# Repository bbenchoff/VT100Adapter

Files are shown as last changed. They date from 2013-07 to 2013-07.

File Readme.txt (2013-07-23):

VT100 to ATX power supply adapter

This project adapts an off-the-shelf computer power supply to replace the power supply found in a Digital VT100 serial terminal.

As of now, this will not work with a VT103, as it does not generate BPOK and BDCOK signals. It should, however, work with the VT101 and VT102.

The terminal is not mounted to the PCB, allowing for positioning in various locations in the power supply bay of the VT100.

Included in this repo are Eagle schematic and board files, Gerbers in OSHPark format, and a BOM with Mouser listings of every component.

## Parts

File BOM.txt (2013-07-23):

Part Value      Device      	Package               Description           			P/N

C1   220uF 50V  CAP_POLPTH1 	CPOL-RADIAL-100UF-25V Capacitor Polarized                                                                                                                                                                                                   
C2   0.01 uF    CAPEZ       	CAP-PTH-SMALLEZ       Capacitor                                                                                                                                                                                                             
J1   ATX24RH    ATX24RH     	ATX24_RIGHT_ANGLE     ATX24 Pin PRT-09498    			Mouser 538-39-30-0240

R1   6.8 Ohm	Resistor			      Wire-wound Resistor			Mouser 756-WHS5-6R8JT075
                                                      
U1   DFBRIDGE   Diode Bridge			                                               	Mouser 625-DF04MA-E3                                                                                                                                                                                    
U2   7824T      7824T       	TO220H                Positive Voltage Regulator	       	Mouser 755-BA17824T                                                                                                                                                                      
X1   X1           	    		              Terminal Block                            Mouser 571-282856-2                                                                                                                                                 
X2   X2           	    		              Terminal Block                            Mouser 571-282856-2

T1		Transformer			      Power Transformers 115/230 6VA 24VCT	Mouser 546-186B24

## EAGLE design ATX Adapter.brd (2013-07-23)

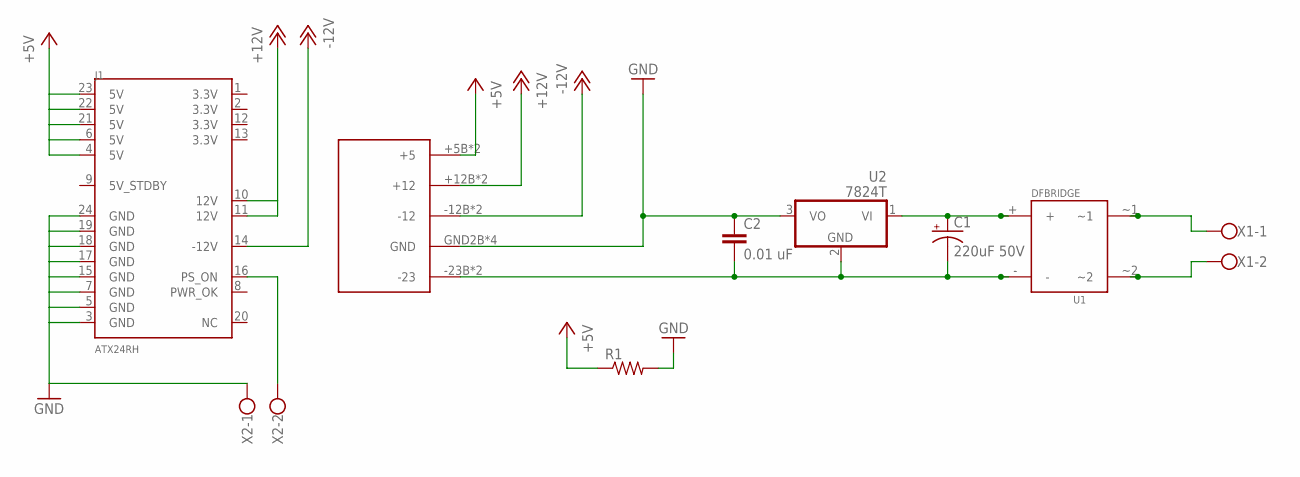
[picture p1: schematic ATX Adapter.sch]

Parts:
C1: 220uF 50V; CPOL-RADIAL-100UF-25V
C2: 0.01 uF; CAP-PTH-SMALLEZ
J1: ATX24RH; ATX24_RIGHT_ANGLE
R1: RESISTORPTH-2W; AXIAL-0.8
U1: DFBRIDGE
U2: 7824T; TO220H
U$1: VT100POWER
X1, X2: W237-102

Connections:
+5V: J1.4 (5V), J1.6 (5V), J1.21 (5V), J1.22 (5V), J1.23 (5V), R1.P$1 (1), U$1.+5B (+5), U$1.+5T (+5)
+12V: J1.10 (12V), J1.11 (12V), U$1.+12B (+12), U$1.+12T (+12)
-12V: J1.14 (-12V), U$1.-12B (-12), U$1.-12T (-12)
GND: C2.1, J1.3 (GND), J1.5 (GND), J1.7 (GND), J1.15 (GND), J1.17 (GND), J1.18 (GND), J1.19 (GND), J1.24 (GND), R1.P$2 (2), U2.3 (VO), U$1.GND2B (GND), U$1.GNDB1 (GND), U$1.GNDT1 (GND), U$1.GNDT2 (GND), X2.1
unnamed: U1.~1, X1.1
unnamed: U1.~2, X1.2
unnamed: C1.1 (+), U1.+, U2.1 (VI)
unnamed: C1.2 (-), C2.2, U1.-, U2.2 (GND), U$1.-23B (-23), U$1.-23T (-23)
unnamed: J1.16 (PS_ON), X2.2

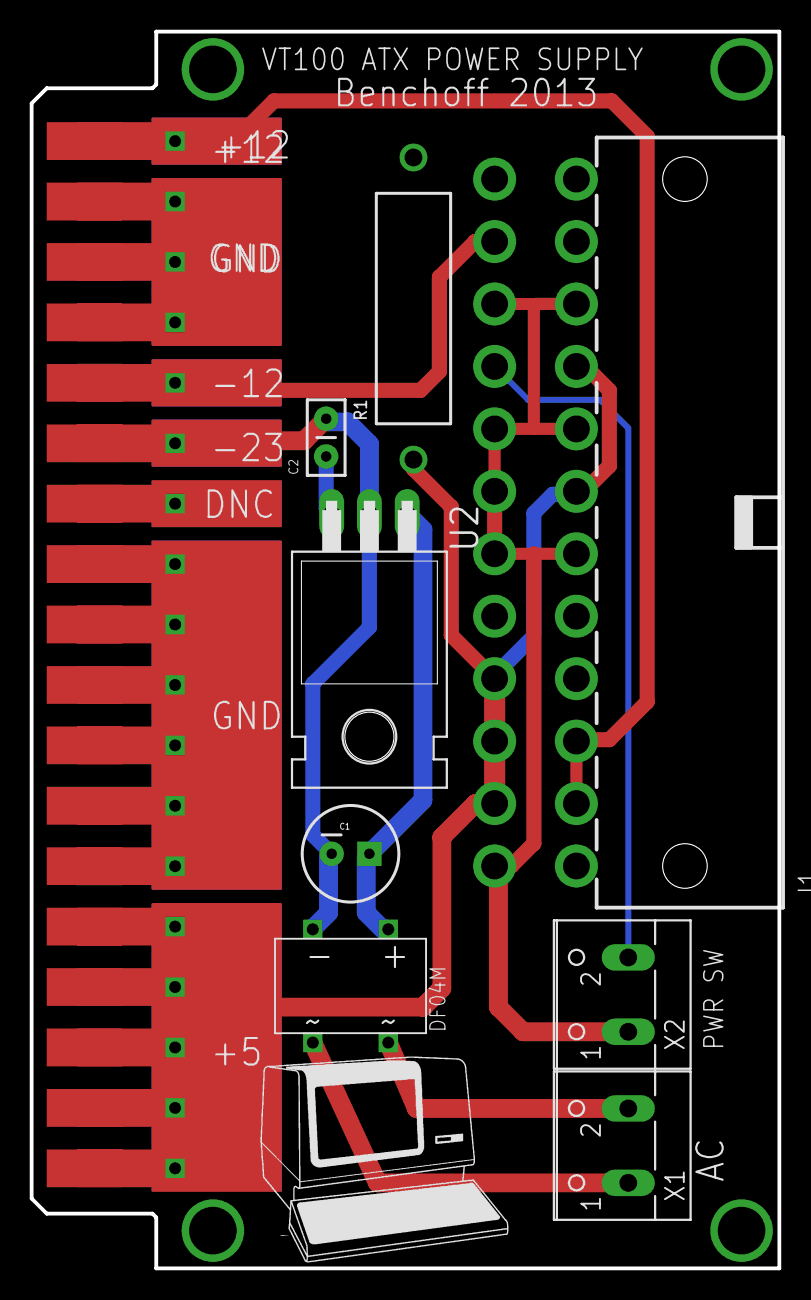
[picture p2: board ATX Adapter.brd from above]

Board: 2 copper layers, 50.3 x 83.2 mm, 9 parts (0 on the bottom side), 9 nets.

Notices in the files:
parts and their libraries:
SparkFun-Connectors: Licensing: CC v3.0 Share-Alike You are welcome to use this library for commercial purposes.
